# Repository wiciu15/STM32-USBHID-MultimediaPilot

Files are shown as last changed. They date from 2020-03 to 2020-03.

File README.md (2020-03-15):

# STM32-USBHID-MultimediaPilot
STM32 based USB device with a joystick to control your media player on PC.
It's a simple USB keyboard with only multimedia keys, and joystick with encoder instead of keys.

Main components are:
- Stm32F103 aka 'blue pill' development board
- ALPS RKJXT1F42001 joystick
- 3D printed enclosure
- firmware with custom USB descriptor based on ST's USB_DEVICE HAL library

Encoder is acting as volume up/down, pushbutton is play/pause key, left/right is next/prev track.


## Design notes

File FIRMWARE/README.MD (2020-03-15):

# STM32 firmware

If you're lazy I provide ready to flash usbhid_firmware.bin file. Flash with your ST-LINK and enjoy.

Source written in STM32CubeIDE 1.3.0.

If you regenerate code using Cube **make a backup** of files in /Middlewares/ST/STM32_USB_Device_Library/Class/HID/
because **Cube will overwrite** them with example report descriptor for USB mouse.

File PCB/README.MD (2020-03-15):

# Schematic and PCB design

b.Cu.pdf is a ready to print copper layer for thermotransfer/exposure

Project files come from KiCAD 5.1.5

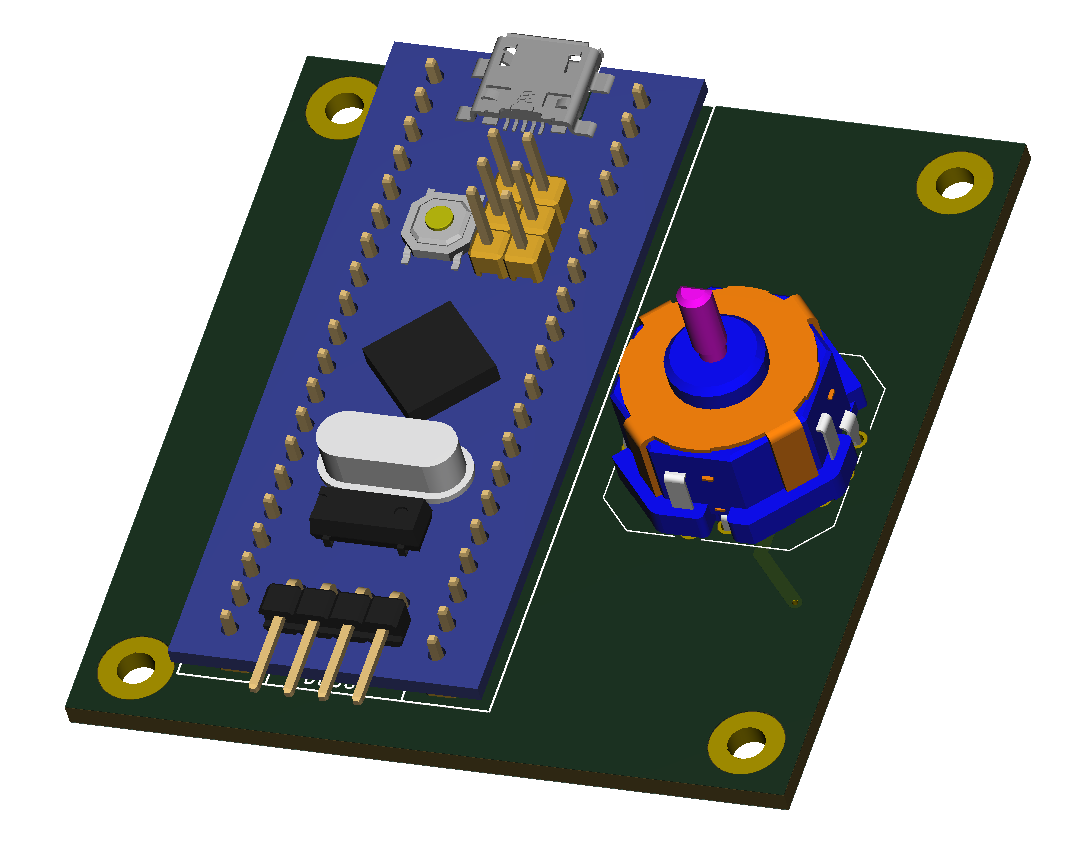
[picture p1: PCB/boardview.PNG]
boardview

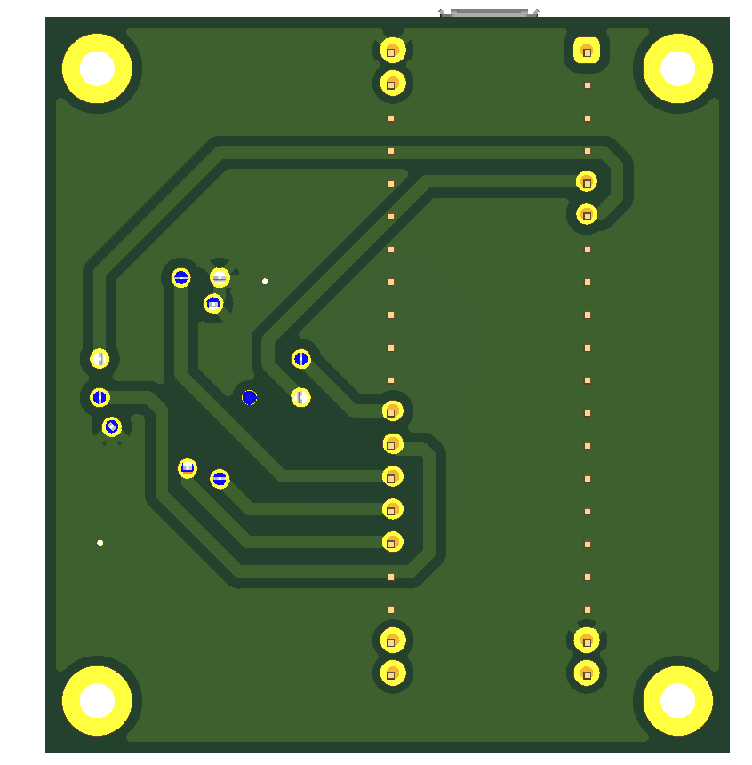
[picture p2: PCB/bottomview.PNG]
bottomboardview


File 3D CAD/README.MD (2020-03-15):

# CAD files

.stl files are ready to be printed

.step file contains project assembly exported from fusion360

If you need editable version of enclosure PM me, I can provide .f3d archive of project or share a project in the cloud.

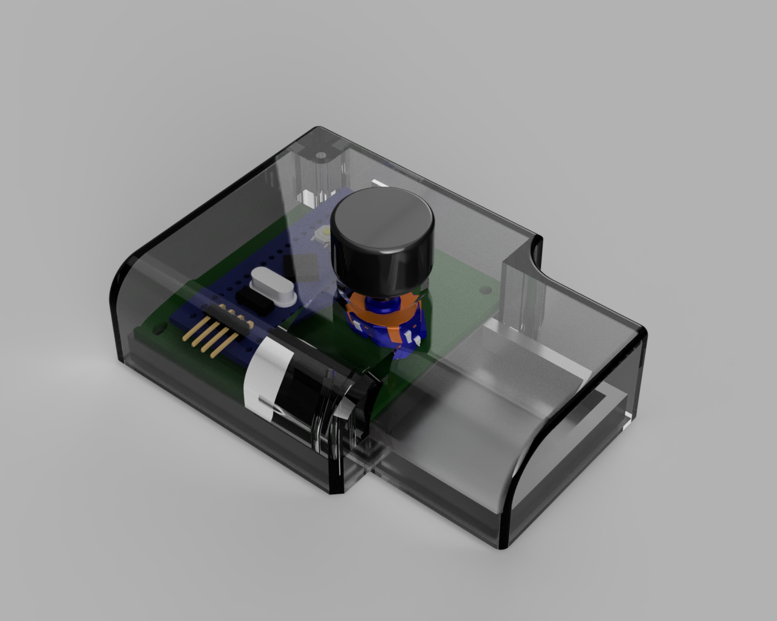
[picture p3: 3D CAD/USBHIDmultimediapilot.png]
render


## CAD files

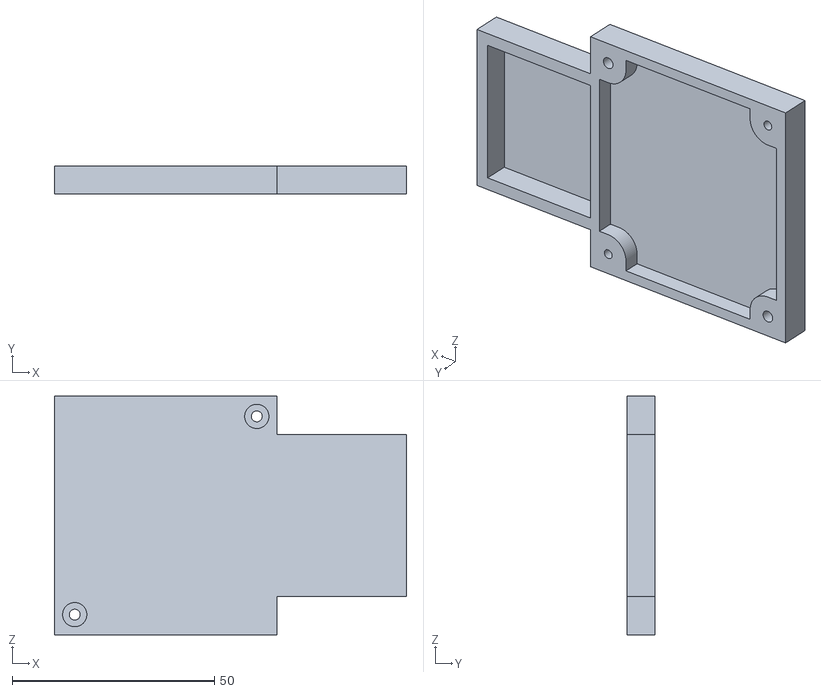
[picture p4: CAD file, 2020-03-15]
3D CAD/Lower.stl
87.0 x 7.00 x 59.0

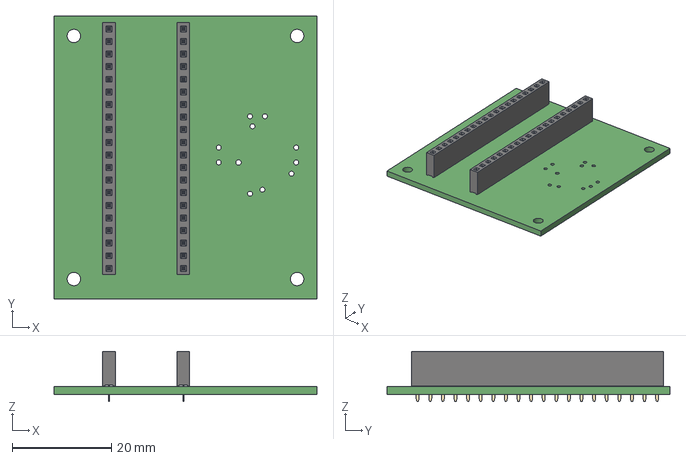
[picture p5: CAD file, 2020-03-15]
PCB/MultimediaPilot.step
53.0 x 57.0 x 10.1 mm

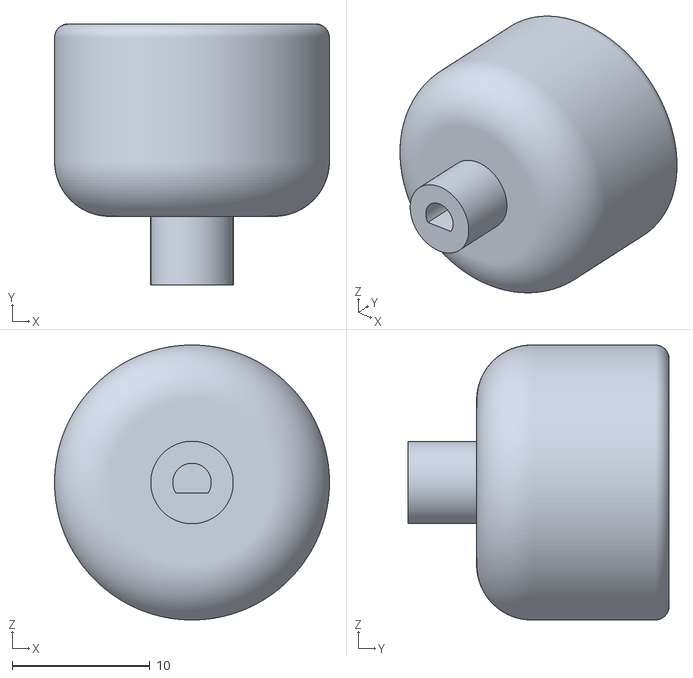
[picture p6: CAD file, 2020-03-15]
3D CAD/Dial.stl
20.0 x 19.0 x 20.0

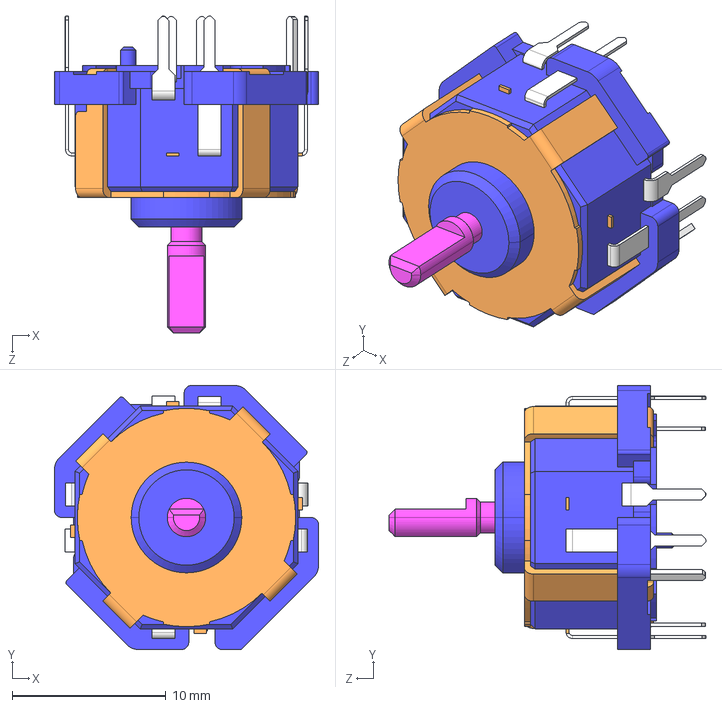
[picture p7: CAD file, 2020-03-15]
PCB/RKJXT1F42001.STEP
17.2 x 17.2 x 20.6 mm

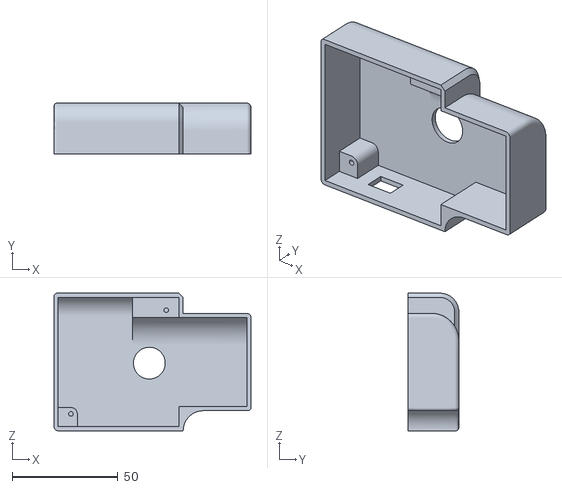
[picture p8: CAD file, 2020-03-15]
3D CAD/Upper.stl
93.0 x 24.0 x 65.0

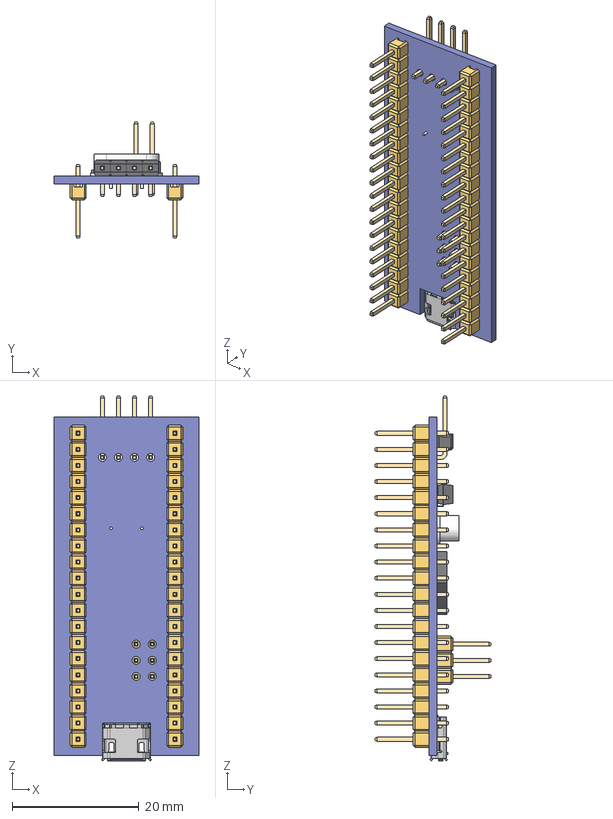
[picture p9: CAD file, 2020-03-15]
PCB/STM32F103C8T6_Blue_Pill v6.step
22.9 x 18.3 x 57.6 mm
Oscillator_HC-49/S
STM32F103C8T6_BluePill_Board
Oscillator_MC-306
STM32_LQFP48
Tactile_SMD_5x5mm
Header_L4_10x4.8
Header_Male_2x3x11.6
Header_Male_1x20x11.6 x 2

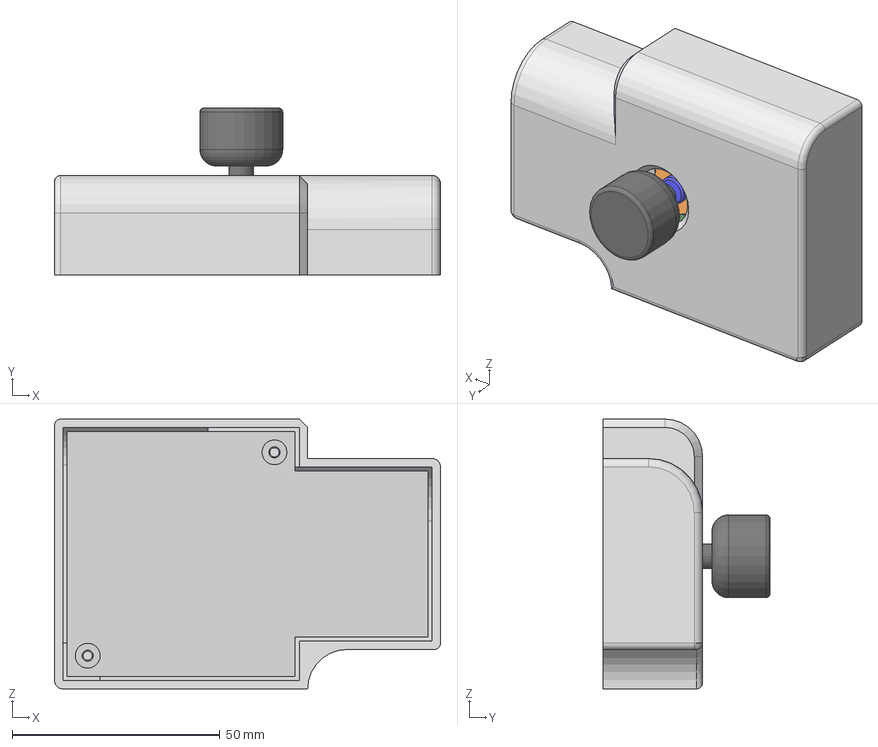
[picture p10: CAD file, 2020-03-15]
3D CAD/USBHID multimedia pilot.step
93.0 x 40.2 x 65.0 mm
RKJXT1F42001
S v1
STM32F103C8T6_BluePill_Board v6
Oscillator_MC-306 v3
STM32_LQFP48 v3
Tactile_SMD_5x5mm v1
micro_usb_socket v1
Header_L4_10x4
Header_Male_2x3x11
Lower
Upper
Dial

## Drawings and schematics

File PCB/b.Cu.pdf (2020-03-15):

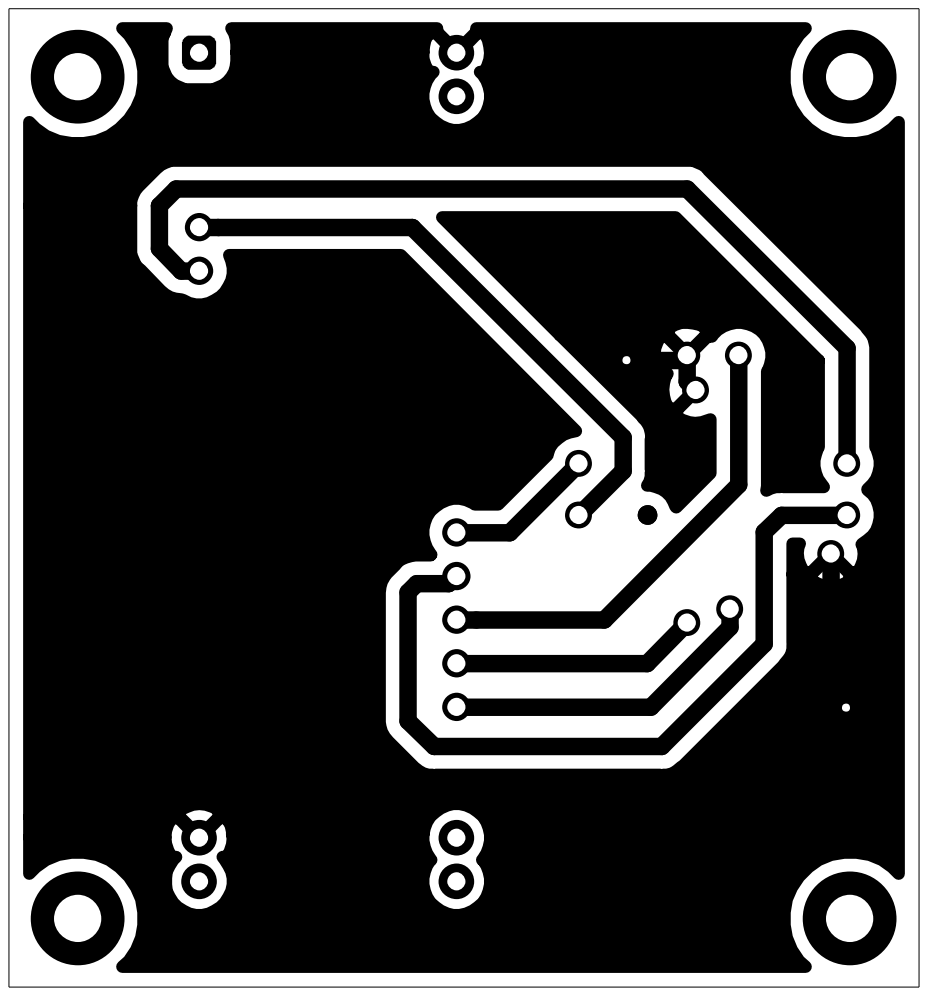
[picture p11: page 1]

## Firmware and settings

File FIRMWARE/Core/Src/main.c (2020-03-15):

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

/* Includes ------------------------------------------------------------------*/
#include "main.h"
#include "usb_device.h"

/* USER CODE BEGIN Includes */
#include "usbd_hid.h"
/* USER CODE END Includes */

/* USER CODE BEGIN PD */
#define HID_REPORT_SIZE 3

#define BUTTON_DEBOUNCE_DELAY_MS 50

//BUTTON DEFINES http://www2.ece.rochester.edu/~parihar/pres/Report_MultiMedia-KB.pdf page11

#define MEDIA_MUTE 0
#define MEDIA_VOLUP 1
#define MEDIA_VOLDOWN 2
#define MEDIA_PLAY_PAUSE 3
#define MEDIA_STOP 4
#define MEDIA_PREV 5
#define MEDIA_NEXT 6
/* USER CODE END PD */

TIM_HandleTypeDef htim1;

/* USER CODE BEGIN PV */
extern USBD_HandleTypeDef hUsbDeviceFS;
uint8_t HID_report[HID_REPORT_SIZE] = {0x01,0,0}; //empty hid report

uint16_t encoderCount=32766; //half of timers resolution (16bit)
uint16_t lastEncoderCount=16383;

uint8_t buttonDebounceDelay=0; //delay between checking button states (button debouncing)
/* USER CODE END PV */

void SystemClock_Config(void);
static void MX_GPIO_Init(void);
static void MX_TIM1_Init(void);
/* USER CODE BEGIN PFP */
void HAL_GPIO_EXTI_Callback(uint16_t GPIO_Pin);

//void USB_Send_Button_Press(uint8_t button);
void CheckButtonsState();
void SetKeyPress(uint8_t key);

/* USER CODE END PFP */

/**
  * @brief  The application entry point.
  * @retval int
  */
int main(void)
{
  /* MCU Configuration--------------------------------------------------------*/

  /* Reset of all peripherals, Initializes the Flash interface and the Systick. */
  HAL_Init();

  /* Configure the system clock */
  SystemClock_Config();

  /* Initialize all configured peripherals */
  MX_GPIO_Init();
  MX_USB_DEVICE_Init();
  MX_TIM1_Init();
  /* USER CODE BEGIN 2 */

  HAL_TIM_Encoder_Start(&htim1, TIM_CHANNEL_ALL);
  __HAL_TIM_SET_COUNTER(&htim1,encoderCount);

  /* USER CODE END 2 */

  /* Infinite loop */
  /* USER CODE BEGIN WHILE */
  while (1)
  {
	  HID_report[1]=0; //0 means none of the buttons pressed

	  ////THIS CODE CAN SUPPORT ONLY 1 KEY AT A TIME, AND VERY SLOW REPEAT WITH LONG PRESS////


	  CheckButtonsState(); //check if any button is pressed and set appropriate bits in HID_report[1]
	  if(HID_report[1]!=0){
		  USBD_HID_SendReport(&hUsbDeviceFS, HID_report, HID_REPORT_SIZE); //send key-press and after 15 ms key-release reports
		  HAL_Delay(400);
		  HID_report[1]=0;
		  USBD_HID_SendReport(&hUsbDeviceFS, HID_report, HID_REPORT_SIZE);
		  HAL_Delay(15);
	  }


	  encoderCount=__HAL_TIM_GET_COUNTER(&htim1)/2; //get encoder absolute position
	  if(encoderCount!=lastEncoderCount){
		  if(encoderCount<lastEncoderCount){SetKeyPress(MEDIA_VOLDOWN);lastEncoderCount-=1;}  //set key press depending on encoder movement direction
		  else{SetKeyPress(MEDIA_VOLUP);lastEncoderCount+=1;}

		  USBD_HID_SendReport(&hUsbDeviceFS, HID_report, HID_REPORT_SIZE);
		  HAL_Delay(15);
		  HID_report[1]=0;
		  USBD_HID_SendReport(&hUsbDeviceFS, HID_report, HID_REPORT_SIZE);
		  HAL_Delay(15);
	  }

	  HAL_Delay(1);

	  /* USER CODE END WHILE */

	  /* USER CODE BEGIN 3 */
  }
  /* USER CODE END 3 */
}

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
/* USER CODE BEGIN 4 */
void HAL_GPIO_EXTI_Callback(uint16_t GPIO_Pin){

}
/*
void USB_Send_Button_Press(uint8_t button){
	HID_report[1] |= 1<<button; // media next http://www2.ece.rochester.edu/~parihar/pres/Report_MultiMedia-KB.pdf page11
	USBD_HID_SendReport(&hUsbDeviceFS, HID_report, HID_REPORT_SIZE);
	HAL_Delay(15);
	HID_report[1] &= ~(1<< button);
	USBD_HID_SendReport(&hUsbDeviceFS, HID_report, HID_REPORT_SIZE);
	HAL_Delay(15);
}*/
void SetKeyPress(uint8_t key){
	HID_report[1] |= 1<<key;
}

void SetKeyRelease(uint8_t key){
	HID_report[1] &= ~(1<< key);
}
void CheckButtonsState(){
	if(!HAL_GPIO_ReadPin(PUSH_GPIO_Port, PUSH_Pin))	{ 							//push input is low when whichever button is pressed
		uint8_t isPushPressed=1;
		if(!HAL_GPIO_ReadPin(RIGHT_GPIO_Port, RIGHT_Pin))	{SetKeyPress(MEDIA_NEXT); isPushPressed=0; }
		if(!HAL_GPIO_ReadPin(LEFT_GPIO_Port, LEFT_Pin))		{SetKeyPress(MEDIA_PREV); isPushPressed=0; }
		if(!HAL_GPIO_ReadPin(UP_GPIO_Port, UP_Pin))			{SetKeyPress(MEDIA_MUTE); isPushPressed=0; }
		if(!HAL_GPIO_ReadPin(DOWN_GPIO_Port, DOWN_Pin))		{SetKeyPress(MEDIA_STOP); isPushPressed=0; }

		if(isPushPressed==1){SetKeyPress(MEDIA_PLAY_PAUSE);}
	}
}

/* USER CODE END 4 */
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


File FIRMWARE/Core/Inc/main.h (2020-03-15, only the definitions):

#define PUSH_Pin GPIO_PIN_0
#define PUSH_GPIO_Port GPIOA
#define PUSH_EXTI_IRQn EXTI0_IRQn
#define UP_Pin GPIO_PIN_1
#define UP_GPIO_Port GPIOA
#define UP_EXTI_IRQn EXTI1_IRQn
#define DOWN_Pin GPIO_PIN_2
#define DOWN_GPIO_Port GPIOA
#define DOWN_EXTI_IRQn EXTI2_IRQn
#define LEFT_Pin GPIO_PIN_3
#define LEFT_GPIO_Port GPIOA
#define LEFT_EXTI_IRQn EXTI3_IRQn
#define RIGHT_Pin GPIO_PIN_4
#define RIGHT_GPIO_Port GPIOA
#define RIGHT_EXTI_IRQn EXTI4_IRQn

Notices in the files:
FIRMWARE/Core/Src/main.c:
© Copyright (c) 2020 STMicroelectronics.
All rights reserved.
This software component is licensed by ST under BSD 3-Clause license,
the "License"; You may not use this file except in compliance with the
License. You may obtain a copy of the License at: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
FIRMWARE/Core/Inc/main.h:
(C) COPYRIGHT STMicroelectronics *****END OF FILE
